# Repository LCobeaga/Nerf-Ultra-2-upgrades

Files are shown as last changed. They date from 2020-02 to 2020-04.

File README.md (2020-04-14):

# Nerf-Ultra-2-upgrades
Modifications for the Nerf Ultra 2 to improve performance

This is essentially a replacement for the Ultra 2 to fire regular sized elite darts. 
Currently there is a single 9 dart replacement cylinder, its retention plate, a pusher, and flywheel cages meant for 130-180 sized motors. 

Other than the actual components of the flywheel cage (i.e. motors, wheels) a stronger spring or a doubled up one can be used for the kit, however it is optional. 
The spring helps with retaining cylinder position WHILE NOT FIRING thus it is prefrence whether your cylinder holds well enough for you. 

I have taken the time to add a parametric feature to the fusion 360 file, so if you want a flywheel spacing that I didnt supply as an stl it should be as simple as putting in the new preffered dimention in a single, highlited and named spot in the parametric menu. 

There are currently two sets of flywheel cages and pushers, original and V2. They both function perfectly, however the V2 has been optimised for fewest parts, and least amount of material (both support and actual print). 

If you like this design but don't have a printer yourself, you can purchase it from Rad Blasters on etsy https://www.etsy.com/shop/RadBlasters.

## Assembly and Blaster Modifications

#### This kit is not just a drop in, you will need to make some permanent modifications to the blaster, however the changes should not impact switching back to the stock hardware.

To make the blaster feed consistently, you'll need to cut away some material near the pusher. 
Below are some photos of how your blaster should look after you make the cuts.

knob removal

knob removal right

peg removal

You will also need to make sure your trigger has the longest possible draw, so make sure it is aligned as below. 

trigger placement

## Grip Insert

Thr grip filler is a single, snap-in part that fills in the front and sides of the grip to make it more comfortable.
The insert works with the stock rev trigger, but the rev trigger goes nearly flush against it, so I will make a new rev trigger soon. 

Below is installation photos.

First place the grip up against the circle at the top of the rev trigger.

slot grip

Then push the tabs over the triangular knob on the bottom.

push in grip

Lightly squeeze the sides to make sure its in and it should be solid. 
To remove pull up on both of the tabs that point to the bottom of the grip and rotate it out.

Future plans for the blaster are:
- brushless motor support, as the flywheel cage is similar in dimention to the cage used on Shadow Price
- rev trigger with a greater slant or curved surface, akin to Bobololo's rev trigger
- cosmetic variants to the barrel that would replace the entire component pair

As a final note, I'm working on my own micro-brushless flywheel hand-cannons so most likely I wont get to everything on this list. 
I do , however, want to "port" (measure and try to copy the blaster into CAD) as much of the blaster as I can so that anyone who is passionate of the blaster can get right into personalizing and modding it, instead of spending days measuring and testing first.

<br />This work is licensed under a <a rel="license" href="http://creativecommons.org/licenses/by-nc-sa/3.0/">Creative Commons Attribution-NonCommercial-ShareAlike 3.0 Unported License</a>.

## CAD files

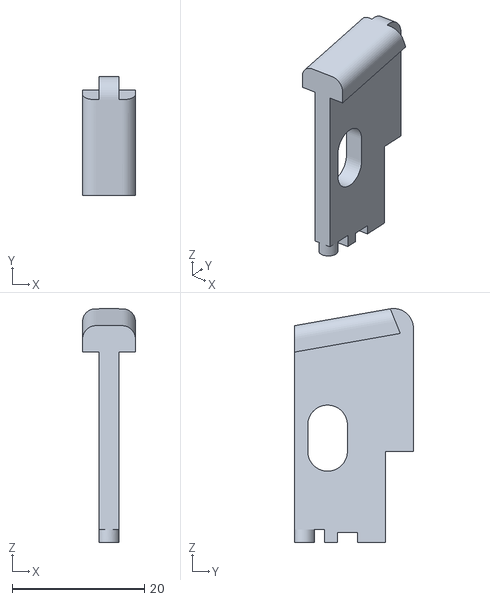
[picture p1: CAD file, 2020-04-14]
Grip Filler/rev trigger.stl
8.00 x 18.0 x 35.4

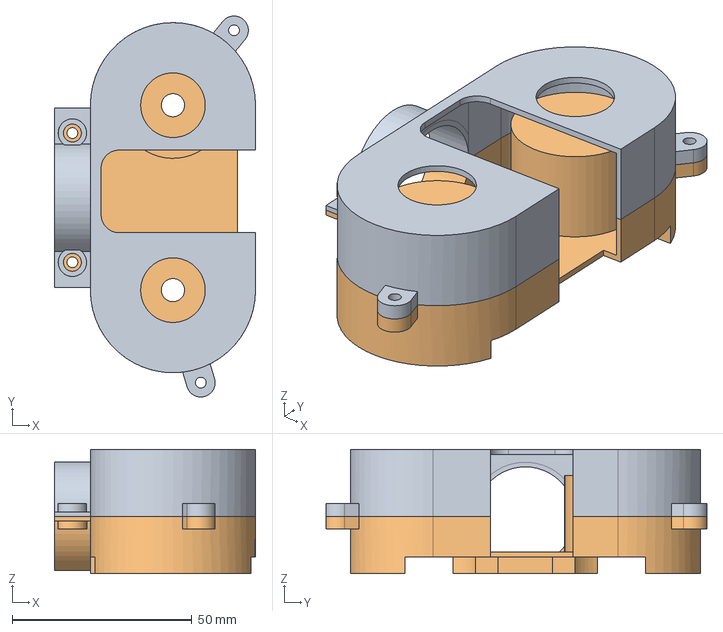
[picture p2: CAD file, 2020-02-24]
Ports/Nerf Ultra 2 cage v5.step
56.0 x 106.1 x 34.6 mm
Mount

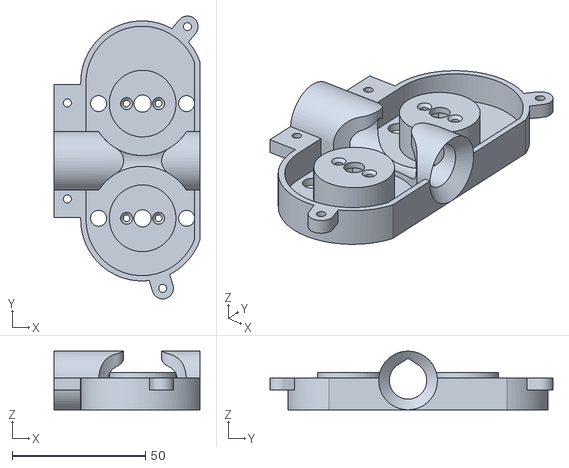
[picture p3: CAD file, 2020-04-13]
regular dart conversion/flywheel cages/43mm mount v2.stl
54.7 x 106.1 x 22.0

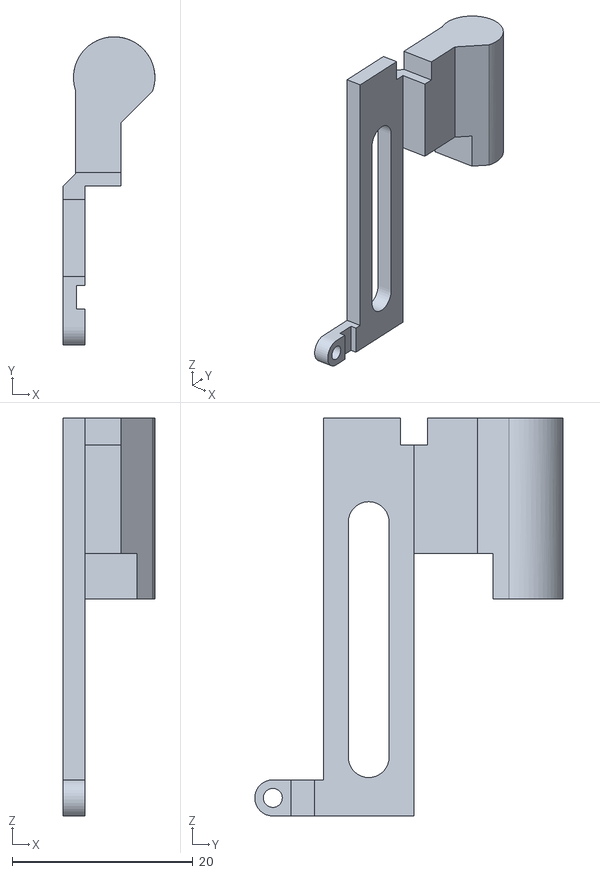
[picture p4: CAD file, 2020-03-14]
regular dart conversion/pusher v3.stl
10.2 x 34.1 x 44.0

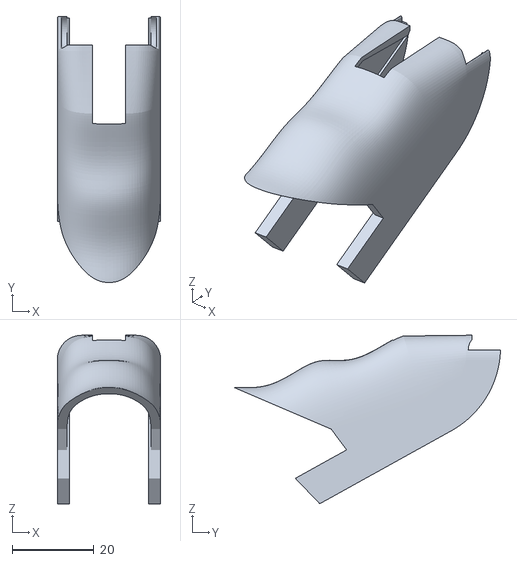
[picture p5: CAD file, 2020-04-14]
Grip Filler/snap fit grip filler.stl
25.3 x 65.1 x 41.2

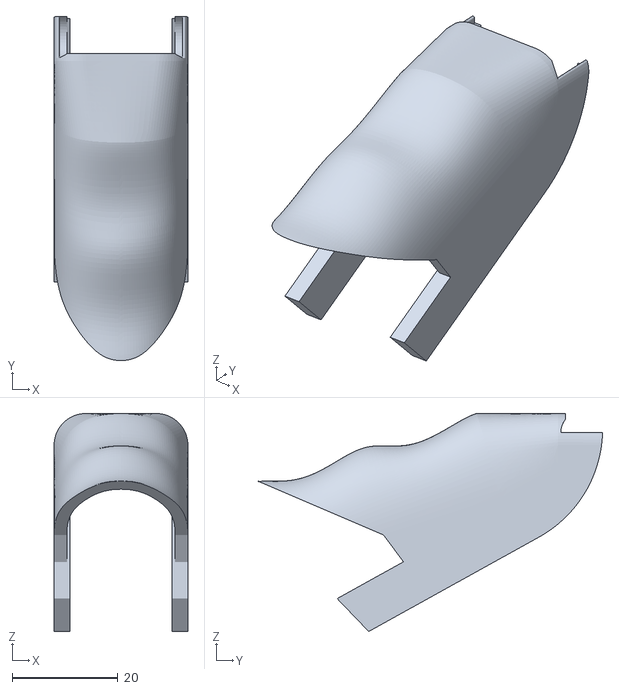
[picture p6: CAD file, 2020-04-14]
Grip Filler/snap fit grip filler-noRevTrigger.stl
25.3 x 65.1 x 41.2

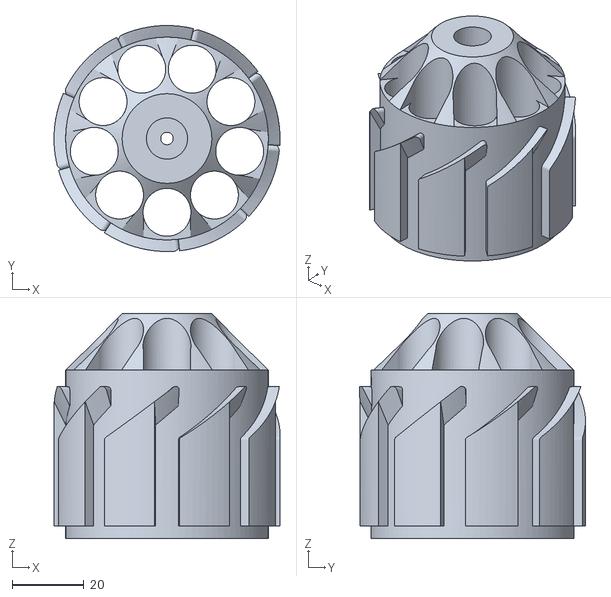
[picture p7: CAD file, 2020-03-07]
regular dart conversion/cylinder.stl
63.0 x 63.0 x 62.8

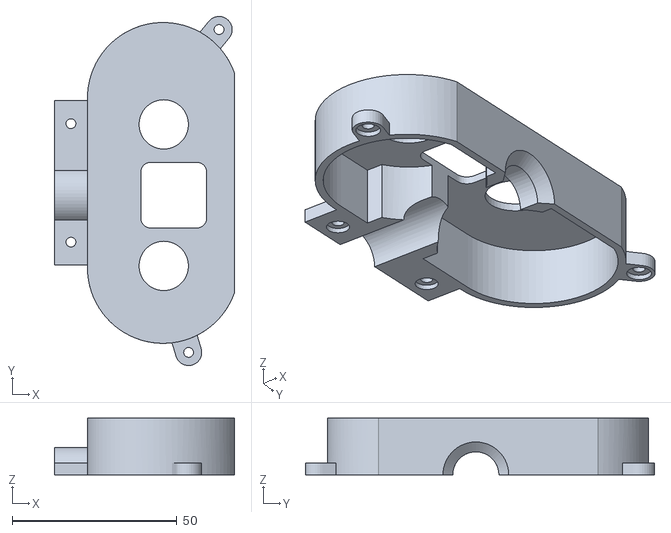
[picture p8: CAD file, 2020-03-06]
regular dart conversion/flywheel cages/43mm cover.stl
54.7 x 106.1 x 17.2

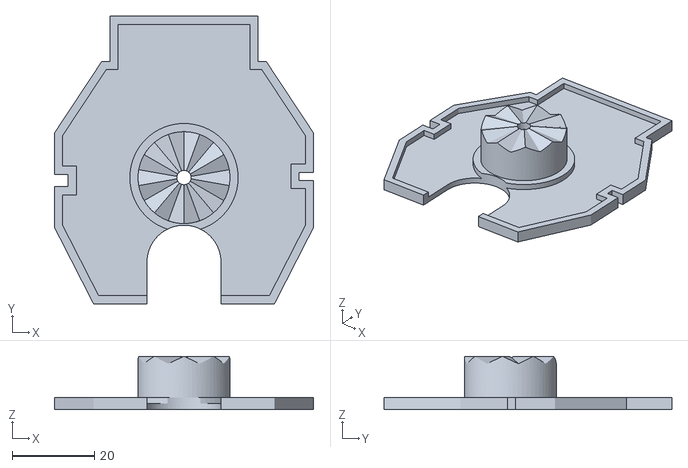
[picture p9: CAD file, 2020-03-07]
regular dart conversion/indexing plate.stl
63.0 x 70.0 x 13.0

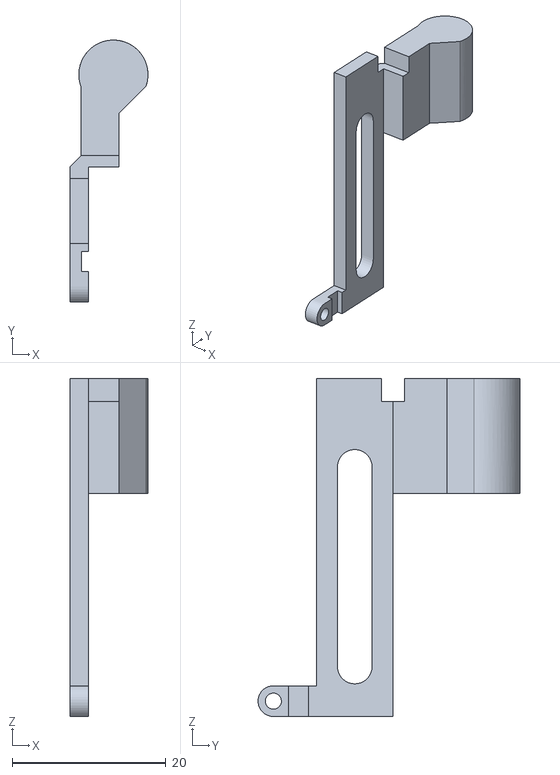
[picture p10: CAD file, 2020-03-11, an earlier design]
regular dart conversion/pusher v2.stl
10.2 x 34.1 x 44.0

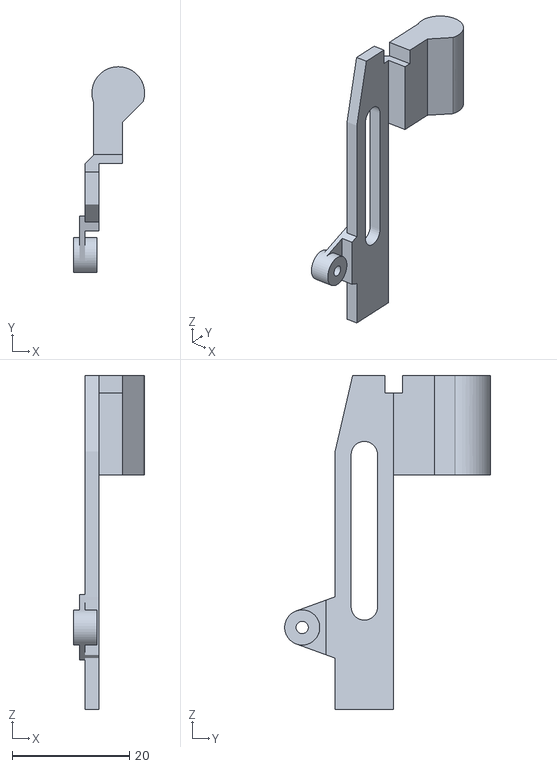
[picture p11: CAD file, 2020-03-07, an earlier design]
regular dart conversion/pusher.stl
12.1 x 35.1 x 57.0

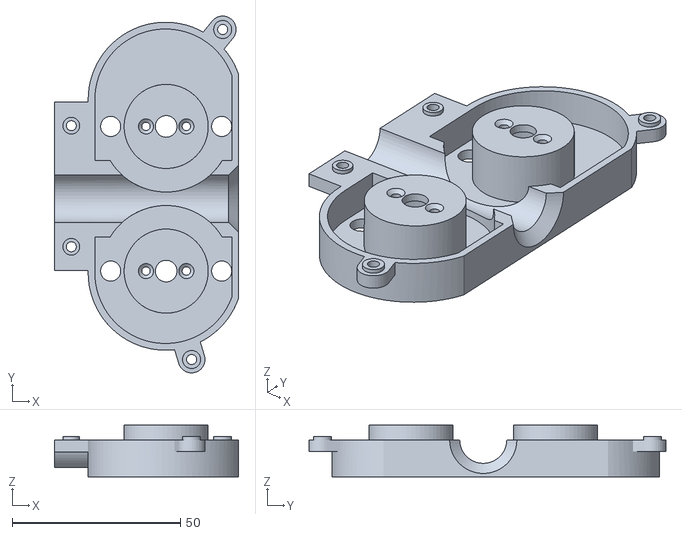
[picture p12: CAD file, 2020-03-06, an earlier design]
regular dart conversion/flywheel cages/43mm mount.stl
54.7 x 106.1 x 15.4

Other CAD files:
regular dart conversion/flywheel cages/42mm mount v2.stl
regular dart conversion/flywheel cages/42.5mm mount v2.stl
regular dart conversion/flywheel cages/41.5mm mount v2.stl
regular dart conversion/flywheel cages/42.5mm cover.stl
regular dart conversion/flywheel cages/42mm cover.stl
regular dart conversion/flywheel cages/41.5mm cover.stl
Grip Filler/Nerf Ultra 2 handle filler.f3d
Ports/Nerf Ultra 2 cage v5.f3d
regular dart conversion/Nerf Ultra 2 regular dart replacement package.f3d
regular dart conversion/flywheel cages/41.5mm mount.stl
regular dart conversion/flywheel cages/42.5mm mount.stl
regular dart conversion/flywheel cages/42mm mount.stl

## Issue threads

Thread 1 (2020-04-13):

Ultra two 43 cage problems

ec128, 2020-04-13:
The 43mm cage v2 one side motor hole is not centered, please fix that, Thanks.

LCobeaga, 2020-04-13:
A constraint was lost at some point, so the holes on the bottom weren't moving with the new parametric. This issue should be fixed for all V2 cages

Closed 2020-04-13.

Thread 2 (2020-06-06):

Stock motor compatibility?

peterberetich, 2020-06-06:
Hi!

This is some fantastic work, I am extremely impressed. I was wondering if the V1 versions of the flywheel cages are compatible with stock motors?

Thank you and I apologize if this is the wrong place to ask this.

LCobeaga, 2020-06-06:
Sadly no. While the V1 appears more like the original cage, it isn't the same geometry, and in the end, the cover piece was redundant. I think blaster tech might sell a version that uses the stock components, but feel free to download the Autodesk Fusion 360 file and make some changes to the mounting and hole diameter there! The V2 is a lot simpler, so I think you would only need to change a few dimensions in there.

Closed 2020-12-19.

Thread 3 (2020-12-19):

How to chose the flywheel cages ?

Saint-Turgod, 2020-12-19:
Hello,

First thing first, thanks a lot for sharing those files. This Nerf Ultra 2 converstion mod and all the accessories (grip filler, rev trigger) are a blessing.

This mod is the first one I do on a flywheel blaster, and I am quite confused on how to select the flywheel cage among all of the one you offer.

What is the difference between the 41.5mm cage and the 43mm one ?
Does this refers to the width of the cages ? Or maybe to the space between the motors ?

Could you help me with this please ?
If for instance I would like to use a Fang ReVAMPed 130 2s Neo Motor, do you know wich cage I could use. Or what cage and motor did you used in you own build ?

Best regards,

Saint-Turgod

PS: In advance sorry about my poor english

LCobeaga, 2020-12-19:
Hello,

The measurement in the name of each cage is the distance between both motor centers, and a lower distance leads to higher FPS. The cages work with all flywheels, so use something like this site, https://suild.com/tools/flywheel-setup-picker , to check what flywheels and distance you should use for your desired performance.

denipo, 2021-02-26:
Want to add to the thread - also start with the words of appreciation of work! This is an awesome job mate thank you so much for this!
This is my first mode for the flywheel blaster, and I do not have any other parts than the 3d printed and stock parts that will come from the blaster.
The question I have:
When I measured stock motors, they are cylindrical and are about 24mm in diameter. I have printed out the largest cage(43mm) and the placeholder for the motor is still too small.. Could I please ask for help with which cage that should be used for the stock flywheels and stock motor?
Best regards
Dennis

LCobeaga, 2021-04-09:
The dimension that defines each motor is the gap between the center of each motor. There is no cage that fits the stock motors in this file set, nor flywheels. It is meant to be used with aftermarket replacement flywheels and motors. I think someone designed a cage for the stock motors that you can purchase if you want to keep with the stock electronics.

Closed 2021-04-09.

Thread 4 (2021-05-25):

Problems with indexing

tt792, 2021-05-25:
Ive printed the parts and fitted them to the blaster, but it seems like the cylinder doesnt always land correctly on a chamber and as such the pusher mushes the dart into the side of the chamber
Do you have any suggestions to fix this?

LCobeaga, 2021-05-25:
The pusher shouldn't be able to move without the cylinder fully indexing, so either there is something gumming up the indexing notches between the plate and cylinder, or much more likely you just need to sand the inside of each barrel. its probably just too rough for the dart to get pushed so it gets squished.

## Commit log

2020-02-27 fixed issues with index locking interface
    [indexing plate.stl]
2020-02-29 thickened front screwport
    [Nerf Ultra 2 regular dart replacement package.f3d]
2020-02-29 screwport change to make printing easier
    [41.5mm cover.stl, 41.5mm mount.stl, 42.5mm cover.stl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]
2020-03-02 larger index plate nob and shorter cylinder walls
    [cylinder.stl, indexing plate.stl]
2020-03-02 added tolerance in screw port interface
    [41.5mm cover.stl, 41.5mm mount.stl, 42.5mm cover.stl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]
2020-03-03 should prevent jamming
    [pusher.stl]
2020-03-03 fillets on rotation mech to reduce clean up
    [cylinder.stl]
2020-03-03 moved from the flywheel cage directory
    [Nerf Ultra 2 regular dart replacement package.f3d]
2020-03-04 discovered and troubleshooted jamming issues
    [cylinder.stl, indexing plate.stl, pusher.stl]
2020-03-04 pusher and new parametric entries for index fixing
    [Nerf Ultra 2 regular dart replacement package.f3d]
2020-03-06 jam clearing hole and better dart funnel
    [41.5mm cover.stl, 41.5mm mount.stl, 42.5mm cover.stl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]
2020-03-07 made knob taller due to teeth not interacting
    [indexing plate.stl]
2020-03-09 pusher optimized for printing, removed cover
    [Nerf Ultra 2 regular dart replacement package.f3d, pusher v2.stl]
2020-03-09 single part, shorter mounts for smaller wheels
    [41.5mm mount v2.stl, 42.5mm mount v2.stl, 42mm mount v2.stl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]
2020-03-10 better chamfer and thicker walls
    [41.5mm mount v2.stl, 42.5mm mount v2.stl, 42mm mount v2.stl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]
2020-03-10 motors sat too low, raised platform
    [41.5mm mount v2.stl, 42.5mm mount v2.stl, 42mm mount v2.stl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]
2020-03-14 helps if v2 is not pushing far enough
    [pusher v3.stl]
2020-04-13 lower motor holes lost constraint, now realigned
    [41.5mm mount v2.stl, 42.5mm mount v2.stl, 42mm mount v2.stl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]
2020-04-14 added grip insert documentation
2020-04-14 bad geometry, needed to remove more areas
    [Nerf Ultra 2 handle filler.f3d, rev trigger.stl]
